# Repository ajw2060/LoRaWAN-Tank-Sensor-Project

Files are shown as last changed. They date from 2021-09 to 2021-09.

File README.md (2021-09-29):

# LoRaWAN-Tank-Sensor-Project
Project files including Schematics, PCB Layouts and code for Tank Sensor modules

The following components are included
1)  KiCad schematics and PCB layouts for the Pump Controller, Tank Top Sensor and Remote switch module.
2)  Micro python code for the Pycom LoPy4 based Tank Top Sensor
3)  Python code for the Raspberry Pi based Pump Controller
4)  Python code for the Raspberry Pi Zero W based remote switch module

The code has been zipped to keep the relevant files together.

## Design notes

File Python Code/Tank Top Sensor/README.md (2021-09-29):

# MillTankSubmersible2021

This is the micropython code for the PyCom Lopy4 microcontroller.  It is intended to do the following.

1) Manage the submersible pressure sensor to detect the depth of water in the tank.
2) Report this water depth along with environmental data via LoRaWAN.

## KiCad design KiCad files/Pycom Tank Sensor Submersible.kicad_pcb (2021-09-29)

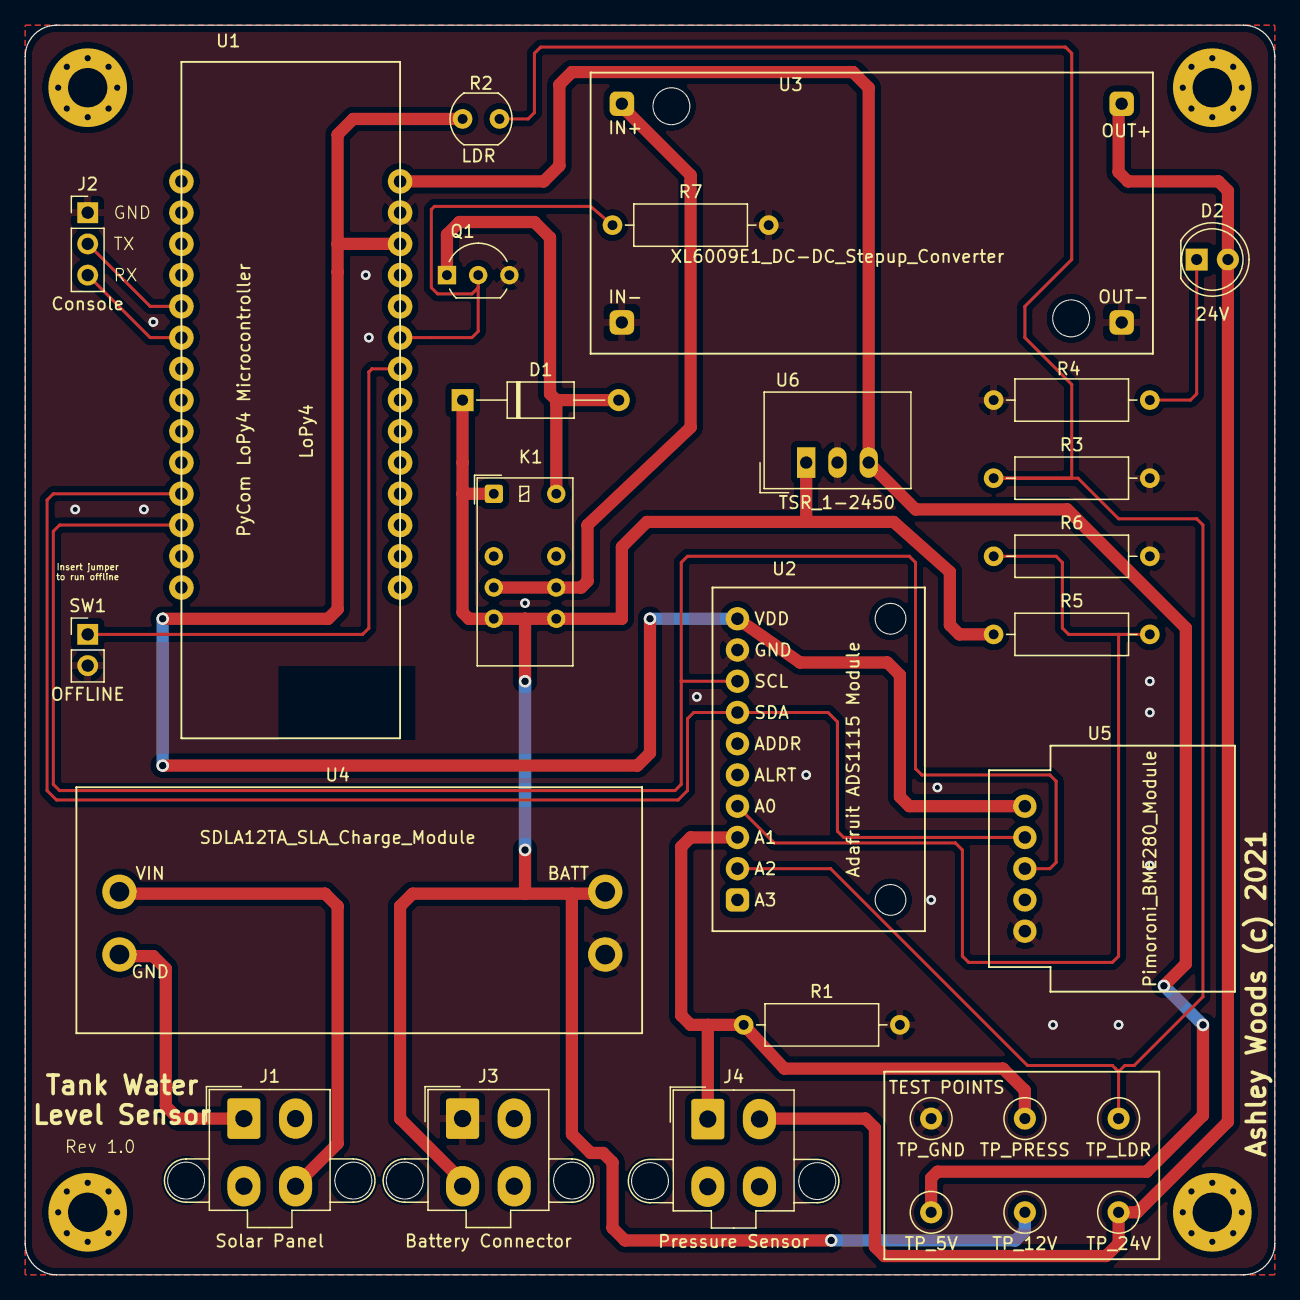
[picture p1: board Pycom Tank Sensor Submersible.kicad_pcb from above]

Board: 2 copper layers, 101.6 x 101.6 mm, 32 parts (0 on the bottom side), 19 nets.

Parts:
D1: D; D_A-405_P12.70mm_Horizontal
D2: +24 LED; LED_D5.0mm
H1, H2, H3, H4: MountingHole; MountingHole_3.2mm_M3_Pad_Via
J1: Solar Panel; Molex_Mini-Fit_Jr_5566-04A2_2x02_P4.20mm_Vertical
J2: Console; PinHeader_1x03_P2.54mm_Vertical
J3: Battery Connector; Molex_Mini-Fit_Jr_5566-04A2_2x02_P4.20mm_Vertical
J4: Pressure Sensor; Molex_Mini-Fit_Jr_5566-04A2_2x02_P4.20mm_Vertical
J5: TP_GND; TestPoint_Loop_D2.60mm_Drill0.9mm_Beaded
J6: TP_5V; TestPoint_Loop_D2.60mm_Drill0.9mm_Beaded
J7: TP_12V; TestPoint_Loop_D2.60mm_Drill0.9mm_Beaded
J8: TP_24V; TestPoint_Loop_D2.60mm_Drill0.9mm_Beaded
J9: TP_PRESS; TestPoint_Loop_D2.60mm_Drill0.9mm_Beaded
J10: TP_LDR; TestPoint_Loop_D2.60mm_Drill0.9mm_Beaded
K1: EC2-12NU; Relay_DPDT_Kemet_EC2
Q1: BS170; TO-92_Inline_Wide
R1: 100R; R_Axial_DIN0309_L9.0mm_D3.2mm_P12.70mm_Horizontal
R2: LDR; R_LDR_5.0x4.1mm_P3mm_Vertical
R3: 1K; R_Axial_DIN0309_L9.0mm_D3.2mm_P12.70mm_Horizontal
R4: 1.5K; R_Axial_DIN0309_L9.0mm_D3.2mm_P12.70mm_Horizontal
R5: 15K; R_Axial_DIN0309_L9.0mm_D3.2mm_P12.70mm_Horizontal
R6: 4.7K; R_Axial_DIN0309_L9.0mm_D3.2mm_P12.70mm_Horizontal
R7: 10K; R_Axial_DIN0309_L9.0mm_D3.2mm_P12.70mm_Horizontal
SW1: OFFLINE; PinHeader_1x02_P2.54mm_Vertical
U1: LoPy4; LoPy_with_headers
U2: Adafruit_ADS1115_Module
U3: XL6009E1_DC-DC_Stepup_Converter; XL6009E1_DC-DC_Converter
U4: SDLA12TA_SLA_Charge_Module; SDLA12TA_Module
U5: Pimoroni_BME280_Module; Pimoroni BME280 Module
U6: TSR_1-2450; Converter_DCDC_TRACO_TSR-1_THT

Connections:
3v3: R2.1, U1.26, U2.10, U5.1
BATTERY+12: D1.1, J3.3, J7.1, K1.1, K1.5, K1.8, R5.1, U4.4, U6.1
BATTLEVEL_SENSE: R5.2, R6.1, U2.4
BOOST24POS: D2.2, J4.2, J8.1, U3.3
BOOST_ENABLE: Q1.2, R7.1, U1.23
BOOST_SUPPLY: K1.4, K1.9, U3.1
BOOST_SWITCH: D1.2, K1.12, Q1.1
CONSOLE_RX: J2.3, U1.6
CONSOLE_TX: J2.2, U1.5
GND: J2.1, J3.1, J5.1, Q1.3, R1.2, R3.2, R4.2, R6.2, R7.2, SW1.2, U1.27, U2.9, U3.2, U3.4, U4.3, U5.5, U6.2
LDR_SENSE: J10.1, R2.2, R3.1, U2.2
unnamed: D2.1, R4.1
OFFLINE_MODE: SW1.1, U1.22
PANEL_NEG: J1.1, U4.2
PANEL_POS: J1.4, U4.1
PRESS_SENSE: J4.1, J9.1, R1.1, U2.3
SCL: U1.12, U2.8, U5.3
SDA: U1.11, U2.7, U5.2
VCC: J6.1, U1.28, U6.3

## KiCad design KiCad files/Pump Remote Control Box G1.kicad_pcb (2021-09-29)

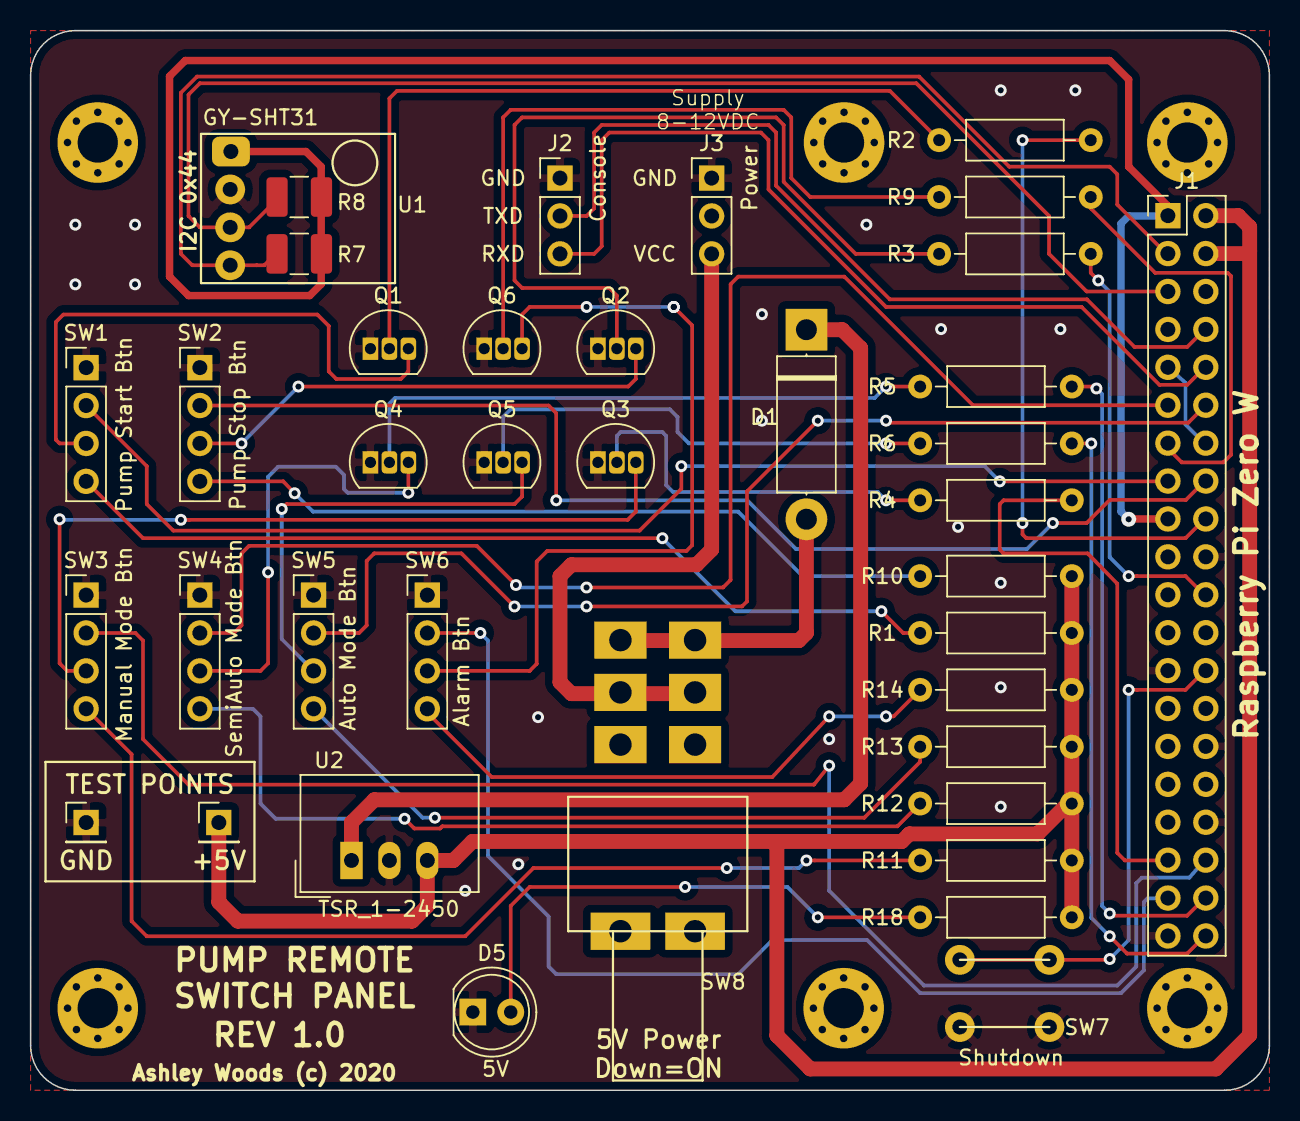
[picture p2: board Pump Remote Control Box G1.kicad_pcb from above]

Board: 2 copper layers, 83.0 x 71.0 mm, 44 parts (0 on the bottom side), 42 nets.

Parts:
D1: D; D_5W_P12.70mm_Horizontal
D5: 5V; LED_D5.0mm
H1, H2, H3, H4, H5, H6: Mount; MountingHole_2.7mm_M2.5_Pad_Via
J1: Raspberry_Pi_2_3; PinHeader_2x20_P2.54mm_Vertical
J2: Serial Console Connector; PinHeader_1x03_P2.54mm_Vertical
J3: Power Input Connector; PinHeader_1x03_P2.54mm_Vertical
Q1, Q2, Q3, Q4, Q5, Q6: P2N2222A; TO-92L_Inline
R1, R10, R11, R12, R13, R14, R18: 220R; R_Axial_DIN0207_L6.3mm_D2.5mm_P10.16mm_Horizontal
R2, R3, R4, R5, R6, R9: 4k3; R_Axial_DIN0207_L6.3mm_D2.5mm_P10.16mm_Horizontal
R7, R8: 10K; R_1210_3225Metric_Pad1.42x2.65mm_HandSolder
SW1: Pump Start Button; PinHeader_1x04_P2.54mm_Vertical
SW2: Pump Stop Button; PinHeader_1x04_P2.54mm_Vertical
SW3: Manual Mode Button; PinHeader_1x04_P2.54mm_Vertical
SW4: Semiauto Mode Button; PinHeader_1x04_P2.54mm_Vertical
SW5: Auto Mode Button; PinHeader_1x04_P2.54mm_Vertical
SW6: Alarm Button; PinHeader_1x04_P2.54mm_Vertical
SW7: Shutdown; PCB Switch RS 479-1413
SW8: SW_DPDT; Switch DPDT Jaycar ST0365
TP1: TP GND; PinHeader_1x01_P2.54mm_Vertical
TP2: TP +5V; PinHeader_1x01_P2.54mm_Vertical
U1: GY_SHT31-Breakout-pycom; GY_SHT31_Breakout
U2: TSR_1-2450; Converter_DCDC_TRACO_TSR-1_THT

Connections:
3v3: J1.1, J1.17, R7.1, R8.1, U1.1
5V: J1.2, J1.4, R1.1, R10.1, R11.1, R12.1, R13.1, R14.1, R18.2, TP2.1, U2.3
Alarm_Button: J1.37, SW6.2
Alarm_Button_LED: J1.13, R9.2
Auto_Mode_Button: J1.12, SW5.2
Auto_Mode_Button_LED: J1.40, R6.2
GND: D5.1, J1.6, J1.9, J1.14, J1.20, J1.25, J1.30, J1.34, J1.39, J2.1, J3.1, Q1.1, Q2.1, Q3.1, Q4.1, Q5.1, Q6.1, SW1.1, SW2.1, SW3.1, SW4.1, SW5.1, SW6.1, SW7.3, SW7.4, TP1.1, U1.2, U2.2
Manual_Mode_Button: J1.36, SW3.2
Manual_Mode_Button_LED: J1.35, R4.2
unnamed: D1.1, U2.1
unnamed: D1.2, SW8.1, SW8.4
unnamed: D5.2, R18.1
unnamed: J3.3, SW8.2, SW8.5
unnamed: Q1.2, R2.1
unnamed: Q1.3, SW1.3
unnamed: Q2.2, R3.1
unnamed: Q2.3, SW2.3
unnamed: Q3.2, R4.1
unnamed: Q3.3, SW3.3
unnamed: Q4.2, R5.1
unnamed: Q4.3, SW4.3
unnamed: Q5.2, R6.1
unnamed: Q5.3, SW5.3
unnamed: Q6.2, R9.1
unnamed: Q6.3, SW6.3
unnamed: R1.2, SW1.4
unnamed: R10.2, SW2.4
unnamed: R11.2, SW3.4
unnamed: R12.2, SW4.4
unnamed: R13.2, SW5.4
unnamed: R14.2, SW6.4
Pump_Start_Button: J1.15, SW1.2
Pump_Start_Button_LED: J1.18, R2.2
Pump_Stop_Button: J1.16, SW2.2
Pump_Stop_Button_LED: J1.22, R3.2
RXD: J1.10, J2.3
SCL: J1.5, R8.2, U1.3
SDA: J1.3, R7.2, U1.4
SHUTDOWN: J1.26, SW7.1, SW7.2
Semiauto_Mode_Button: J1.11, SW4.2
Semiauto_Mode_Button_LED: J1.38, R5.2
TXD: J1.8, J2.2

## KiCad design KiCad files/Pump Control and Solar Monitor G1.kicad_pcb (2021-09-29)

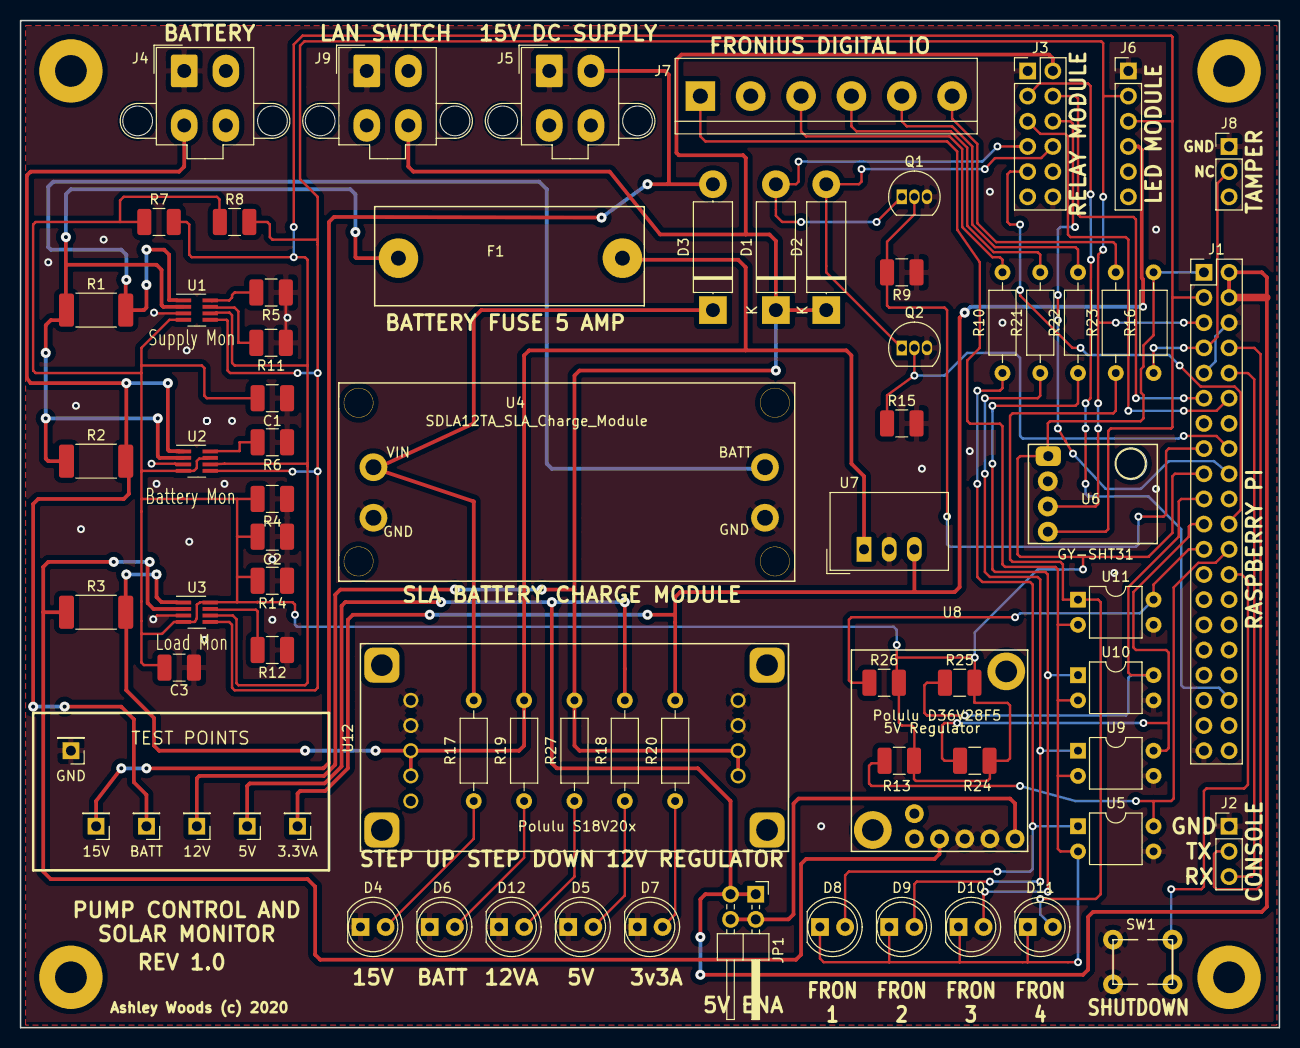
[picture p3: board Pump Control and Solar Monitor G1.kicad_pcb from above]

Board: 2 copper layers, 127.0 x 101.6 mm, 74 parts (0 on the bottom side), 50 nets.

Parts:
C1, C2, C3: 0.1uF; C_1210_3225Metric_Pad1.42x2.65mm_HandSolder
D1, D2: FLYBACK DIODE; D_5W_P12.70mm_Horizontal
D3: Polarity Protection; D_5W_P12.70mm_Horizontal
D4: 15V Present; LED_D5.0mm
D5: 5V Present; LED_D5.0mm
D6: BATTERY Present; LED_D5.0mm
D7: 3v3AUX Present; LED_D5.0mm
D8: Fron1; LED_D5.0mm
D9: Fron2; LED_D5.0mm
D10: Fron3; LED_D5.0mm
D11: Fron4; LED_D5.0mm
D12: 12VA Supply; LED_D5.0mm
F1: Fuse 5 AMP; Wuth Electronik PCB TTH Fuse Holder
J1: Raspberry_Pi_2_3; PinHeader_2x20_P2.54mm_Vertical
J2: Serial Console Connector; PinHeader_1x03_P2.54mm_Vertical
J3: Switch Module Connector; PinHeader_2x06_P2.54mm_Vertical
J4: Battery Connector; Molex_Mini-Fit_Jr_5566-04A2_2x02_P4.20mm_Vertical
J5: DC Power Supply Conector; Molex_Mini-Fit_Jr_5566-04A2_2x02_P4.20mm_Vertical
J6: LED Module Connector; PinHeader_1x06_P2.54mm_Vertical
J7: Plug in Screw_Terminal; TerminalBlock_bornier-6_P5.08mm
J8: Tamper Switch Connector; PinHeader_1x03_P2.54mm_Vertical
J9: Netgear Power; Molex_Mini-Fit_Jr_5566-04A2_2x02_P4.20mm_Vertical
JP1: 5V Enable Jumper; PinHeader_2x02_P2.54mm_Horizontal_DualConnected
Q1, Q2: BS170; TO-92_Inline
R1, R2, R3: 0.1R; R_2512_6332Metric_Pad1.52x3.35mm_HandSolder
R4, R5, R6, R7, R8, R9, R11, R12, R13, R14, R15, R24, R25, R26: 10K; R_1210_3225Metric_Pad1.42x2.65mm_HandSolder
R10, R21, R22, R23: 540R; R_Axial_DIN0207_L6.3mm_D2.5mm_P10.16mm_Horizontal
R16: 10K; R_Axial_DIN0207_L6.3mm_D2.5mm_P10.16mm_Horizontal
R17, R20: 1K; R_Axial_DIN0207_L6.3mm_D2.5mm_P10.16mm_Horizontal
R18: 220R; R_Axial_DIN0207_L6.3mm_D2.5mm_P10.16mm_Horizontal
R19, R27: 820R; R_Axial_DIN0207_L6.3mm_D2.5mm_P10.16mm_Horizontal
SW1: PCB_Switch_RS479-1413; PCB Switch RS 479-1413
TP1: TP GND; PinHeader_1x01_P2.54mm_Vertical
TP2: TP 15V; PinHeader_1x01_P2.54mm_Vertical
TP3: TP Battery; PinHeader_1x01_P2.54mm_Vertical
TP4: TP 12VA; PinHeader_1x01_P2.54mm_Vertical
TP5: TP 5V; PinHeader_1x01_P2.54mm_Vertical
TP6: TP 3v3A; PinHeader_1x01_P2.54mm_Vertical
U1, U2, U3: INA219AIDCNR; SOT-23-8_Handsoldering
U4: SDLA12TA_SLA_Charge_Module; SDLA12TA_Module
U5, U9, U10, U11: PC817; DIP-4_W7.62mm
U6: GY_SHT31 Module; GY_SHT31_Breakout
U7: TSR_1-2433; Converter_DCDC_TRACO_TSR-1_THT
U8: Polulu D36V28F5 5V Regulator; Polulu_D36V28F5_Regulator
U12: Polulu_S18V20F12_Voltage_Regulator; Polulu_S18V20x_Regulators

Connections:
3v3: C1.2, C2.2, C3.2, J1.1, J1.17, R4.2, R7.1, R8.1, R13.2, R14.2, R16.2, R24.2, R25.2, R26.2, U1.4, U2.4, U2.7, U3.4, U3.8, U6.1
5V: J1.2, J1.4, JP1.1, R18.2, TP5.1
+3.3VA: J6.4, R20.2, TP6.1, U7.3
+12VA: D1.1, D2.1, J3.2, J9.4, R27.2, TP4.1, U12.6, U12.7
+15V: D3.1, R17.2, U4.1
AC_Phase1_Present: J1.36, J3.3
AC_Phase2_Present: J1.11, J3.4
AC_Phase3_Present: J1.12, J3.5
BATTERY+: J4.3, R2.2, TP3.1, U2.1
BATTERY_SUPPLY: F1.1, R3.2, R19.2, U3.1, U7.1, U12.3, U12.4
FRONIUS_1: J1.24, R13.1, U5.4
FRONIUS_2: J1.21, R24.1, U9.4
FRONIUS_3: J1.19, R25.1, U10.4
FRONIUS_4: J1.23, R26.1, U11.4
FRONIUS_GND: D8.1, D9.1, D10.1, D11.1, J7.1, U5.2, U9.2, U10.2, U11.2
FRONIUS_RAW_1: J7.3, R10.2
FRONIUS_RAW_2: J7.4, R21.2
FRONIUS_RAW_3: J7.5, R22.2
FRONIUS_RAW_4: J7.6, R23.2
GND: C1.1, C2.1, C3.1, D4.1, D5.1, D6.1, D7.1, D12.1, J1.6, J1.9, J1.14, J1.20, J1.25, J1.30, J1.34, J1.39, J2.1, J3.1, J3.12, J4.1, J5.1, J6.1, J8.1, J9.1, Q1.3, Q2.3, R4.1, R5.1, R6.1, R9.1, R11.1, R12.1, R14.1, R15.2, SW1.3, SW1.4, TP1.1, U1.3, U2.3, U3.3, U4.2, U4.3, U5.3, U6.2, U7.2, U8.4, U8.5, U9.3, U10.3, U11.3, U12.1, U12.2, U12.8, U12.9
unnamed: D3.2, J5.2, TP2.1
unnamed: D4.2, R17.1
unnamed: D5.2, R18.1
unnamed: D6.2, R19.1
unnamed: D7.2, R20.1
unnamed: D8.2, R10.1, U5.1
unnamed: D9.2, R21.1, U9.1
unnamed: D10.2, R22.1, U10.1
unnamed: D11.2, R23.1, U11.1
unnamed: D12.2, R27.1
unnamed: F1.2, R1.1, R2.1, U1.2, U2.2
unnamed: JP1.2, U8.6
unnamed: R1.2, U1.1, U4.4
unnamed: R3.1, U3.2, U8.3
unnamed: R5.2, U1.8
unnamed: R6.2, U2.8
unnamed: R11.2, U1.7
unnamed: R12.2, U3.7
PUMP_FAULT: J1.22, J3.9
PUMP_RUNNING: J1.18, J3.6
PUMP_START_PULSE: J1.15, Q1.2, R9.2
PUMP_START_RELAY: D1.2, J3.7, Q1.1
PUMP_STOP_PULSE: J1.16, Q2.2, R15.1
PUMP_STOP_RELAY: D2.2, J3.8, Q2.1
RXD: J1.10, J2.3
SCL: J1.5, J6.2, R8.2, U1.5, U2.5, U3.5, U6.3
SDA: J1.3, J6.3, R7.2, U1.6, U2.6, U3.6, U6.4
SHUTDOWN: J1.26, SW1.1, SW1.2
TAMPER: J1.7, J8.2, R16.1
TXD: J1.8, J2.2

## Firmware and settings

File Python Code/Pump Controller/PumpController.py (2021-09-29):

# This script will do the following
# - monitor the various GPIO on the Pi for changes and act accordingly


# Changes
# 2020-10-24    Initial version.  This was added under Jupyter.
# 2020-10-31    Added operation mode feature for manual/semi/auto modes receivable via MQTT.
# 2020-11-05    Added subscriber for tank level data via MQTT.
# 2021-07-01    Added better error handler to received MQTT message for tank water level messages.
# 2021-07-18	Added log rotation.
# 2021-07-21    Added tank data keys to status dictionary so this gets reported in status updates also.
# 2021-07-27    Added more logging to pump start/stop processing in automatic mode (to show variables at entry)
# 2021-07-27    Added 'pump turn off' processing in automatic mode.
# 2021-07-28    Simplified logging around receipt of command messages.

from gpiozero import Button# import button from the Pi GPIO library
#from gpiozero import DigitalOutputDevice
#from gpiozero import DigitalInputDevice
from gpiozero import OutputDevice
from gpiozero import CPUTemperature

from ina219 import INA219
from ina219 import DeviceRangeError

import time

import os # imports OS library for Shutdown control
import logging
import logging.handlers
import platform
import sys
from signal import pause
import yaml
import json
import paho.mqtt.client as mqtt
import pprint

import datetime
import threading
import schedule

import smbus

#import socket
#import asyncio



# ---- Define the GPIO pins used by each sense or control line
# The shutdown_button on GPIO7 (Pin 26) is not initialised here as it is used in the separate shutdown script.
phase1_present_sense = Button(16)       #Pin 36
phase2_present_sense = Button(17)       #Pin 11
phase3_present_sense = Button(18)       #Pin 12

pump_running_sense = Button(24)         #Pin 18
pump_fault_sense = Button(25)           #Pin 22

tamper_switch_sense = Button(4)         #Pin 7
fronius_digital1_sense = Button(8)      #Pin 24
fronius_digital2_sense = Button(9)      #Pin 21
fronius_digital3_sense = Button(10)     #Pin 19
fronius_digital4_sense = Button(11)     #Pin 23

pump_start_pulse = OutputDevice(22, active_high=True, initial_value=False, pin_factory=None)       #Pin 15
pump_stop_pulse = OutputDevice(23, active_high=True, initial_value=False, pin_factory=None)        #Pin 16



# ---- Scheduling timers
# next_run_hourly = time.time()
# run_interval_hourly = 3600              # To schedule things every hour (but not necessarily on the hour)


# ---------- Configuration load from YAML -----------------------------------------------------------------------------
def yaml_loader(filepath):
    try:
        with open(filepath, "r") as file_descriptor:
            config_data = yaml.load(file_descriptor, Loader=yaml.FullLoader)    # Should avoid the unsafe warning
        return config_data
    except:
        print(f"ERROR 5.  Unable to open the YAML configuration file at {filepath}.")
        exit(5)


# ---------- Get the temperature and humidity from the SHT31 sensor ---------------------------------------------------
def getEnclosureTempHumi():
    #print("Getting enclosure temperature and humidity from SHT31 sensor.")
    # Get I2C bus
    bus = smbus.SMBus(1)

    # SHT31 address, 0x44(68)
    bus.write_i2c_block_data(0x44, 0x2C, [0x06])
    time.sleep(0.5)

    # SHT31 address, 0x44(68)
    # Read data back from 0x00(00), 6 bytes
    # Temp MSB, Temp LSB, Temp CRC, Humididty MSB, Humidity LSB, Humidity CRC
    data = bus.read_i2c_block_data(0x44, 0x00, 6)

    # Convert the data
    temp = data[0] * 256 + data[1]
    cTemp = -45 + (175 * temp / 65535.0)
    humidity = 100 * (data[3] * 256 + data[4]) / 65535.0

    # Print the results
    #print("..SHT31 Temperature : %.1f C" %cTemp)
    #print("..SHT31 Humidity    : %.0f %%RH" %humidity)

    # And stuff these into the dictionary
    system_status['environment_state']['enclosure_temperature'] = format(cTemp,'.1f')
    system_status['environment_state']['enclosure_humidity'] = format(humidity,'.0f')


# ---- Get system uptime ----------------------------------------------------------------------------------------------
def get_system_uptime():
    with open('/proc/uptime', 'r') as f:
        uptime_seconds = float(f.readline().split()[0])
        return int(uptime_seconds)


# ---------- Get Raspberry Pi CPU Temperature -------------------------------------------------------------------------
def getCpuTemperature():
    #print("Getting CPU temperature from Raspberry Pi CPU.")
    cpu = CPUTemperature()
    #print('..CPU  temperature  : {}C'.format(cpu.temperature))
    # And stuff it into the dictionary
    system_status['environment_state']['cpu_temperature'] = format(cpu.temperature,'.1f')


# ---------- Publish a generic environmental alarm --------------------------------------------------------------------
def publishEnvironmentAlarm(alarmNumber, alarmState):
    # This will ultimately publish an environment alarm
    #print("XXXXXXXXX - Environment alarm publish stub.  Alarm No=[" + str(alarmNumber) + "].  Alarm State =[" + str(alarmState) +"]")
    '''
        Received parameters are as follows.
        alarmNumber = alarm number
        alarmState.  1=New alarm.  0=Cleared alarm.
    '''
    logger.debug("Publish the alarm message.")

    publish_generic_message('Alarm Condition Detected', topic_pump_status, system_status)


# ---------- Now check if we have any alarm conditions present that need to be reported -------------------------------
def checkForAlarms():
    logger.debug('Running a check of all environment conditions (temp, humidity, sensors, etc) now.')
    '''
        There are many possible alarm conditions to inspect.
        Each one is done individually and a message is published for fresh alarms and cleared alarms (but not for ongoing alarms).
        '''
    checkAlarm01()      # Enclosure temperature
    checkAlarm02()      # Enclosure humidity
    checkAlarm03()      # CPU Temperature
    checkAlarm04()      # Still receiving updates from water level sensor
    checkAlarm05()      # Battery voltage
    checkAlarm06()      # Battery is not discharging


# ---------- Alarm check 01 - Enclosure over temperature --------------------------------------------------------------
def checkAlarm01():
    #logger.debug('.Alarm check 01 - Check for enclosure over-temperature alarm.')
    global enclosure_temp_alarm_base_value
    global enclosure_temp_alarm_recovery_value
    global enclosure_temp_alarm_working_value

    if float(system_status['environment_state']['enclosure_temperature']) < enclosure_temp_alarm_working_value and not system_status['alarms']['enclosure_overtemperature']:
        # All good and nothing to do
        #logger.debug(f"..NORMAL.  Enclosure temperature [{float(system_status['environment_state']['enclosure_temperature']):.1f}] is below threshold of [{float(enclosure_temp_alarm_working_value):.1f}].")
        pass

    elif float(system_status['environment_state']['enclosure_temperature']) >= enclosure_temp_alarm_working_value and not system_status['alarms']['enclosure_overtemperature']:
        # This is a fresh over temperature alarm.  Set the enclosure over-temp alarm flag and publish an alarm.
        logger.debug(f"..NEW ALARM.  Enclosure temperature [{float(system_status['environment_state']['enclosure_temperature']):.1f}] is at or above threshold of [{float(enclosure_temp_alarm_working_value):.1f}].")
        system_status['alarms']['enclosure_overtemperature'] = True
        publishEnvironmentAlarm(1,1)
        # Bump the threshold down to introduce hysterisis for recovery.
        logger.debug(f"..Hysterisis lowering the over-temp alarm threshold from [{enclosure_temp_alarm_working_value:.1f}] to [{enclosure_temp_alarm_recovery_value:.1f}].")
        enclosure_temp_alarm_working_value = enclosure_temp_alarm_recovery_value

    elif float(system_status['environment_state']['enclosure_temperature']) >= enclosure_temp_alarm_working_value and system_status['alarms']['enclosure_overtemperature']:
        # This constitutes an ongoing alarm which does not need to be published again because it has already been done when the condition was first detected.
        logger.debug(f"..CONTINUED ALARM.  Enclosure temperature [{float(system_status['environment_state']['enclosure_temperature']):.1f}] remains above threshold of [{float(enclosure_temp_alarm_working_value):.1f}].")

    elif float(system_status['environment_state']['enclosure_temperature']) < enclosure_temp_alarm_working_value and system_status['alarms']['enclosure_overtemperature']:
        # This is the recovery of an ongoing alarm.  Clear the enclosure over-temp alarm flag and publish a message to indicate recovery.
        logger.debug(f"..CLEARED ALARM.  Enclosure temperature [{float(system_status['environment_state']['enclosure_temperature']):.1f}] is now below threshold of [{float(enclosure_temp_alarm_working_value):.1f}].")
        system_status['alarms']['enclosure_overtemperature'] = False
        publishEnvironmentAlarm(1,0)
        # Restore threshold temperature.
        logger.debug(f"..Hysterisis restoring the over-temp alarm threshold from [{enclosure_temp_alarm_working_value:.1f}] to [{enclosure_temp_alarm_base_value:.1f}].")
        enclosure_temp_alarm_working_value = enclosure_temp_alarm_base_value

    else:
        #logging.error("ERROR 101.  Problem with interrogating enclosure temperature.")
        print("ERROR 101.  Problem with interrogating enclosure temperature.")


# ---------- Alarm check 02 - Enclosure over humidity -----------------------------------------------------------------
def checkAlarm02():
    #logger.debug('.Alarm check 02 - Check for enclosure over-humidity alarm.')
    global enclosure_humidity_alarm_base_value
    global enclosure_humidity_alarm_recovery_value
    global enclosure_humidity_alarm_working_value

    if float(system_status['environment_state']['enclosure_humidity']) < enclosure_humidity_alarm_working_value and not system_status['alarms']['enclosure_overhumidity']:
        # All good and nothing to do
        #logger.debug(f"..NORMAL.  Enclosure humidity [{float(system_status['environment_state']['enclosure_humidity']):.0f}] is below threshold of [{float(enclosure_humidity_alarm_working_value):.0f}].")
        pass

    elif float(system_status['environment_state']['enclosure_humidity']) >= enclosure_humidity_alarm_working_value and not system_status['alarms']['enclosure_overhumidity']:
        # This is a fresh over humidity alarm.  Set the enclosure over-humidity alarm flag and publish an alarm.
        logger.debug(f"..NEW ALARM.  Enclosure humidity [{float(system_status['environment_state']['enclosure_humidity']):.1f}] is at or above threshold of [{float(enclosure_humidity_alarm_working_value):.1f}].")
        system_status['alarms']['enclosure_overhumidity'] = True
        publishEnvironmentAlarm(2,1)
        # Bump the threshold down to introduce hysterisis for recovery.
        logger.debug(f"..Hysterisis lowering the over-humidity alarm threshold from [{enclosure_humidity_alarm_working_value:.0f}] to [{enclosure_humidity_alarm_recovery_value:.0f}].")
        enclosure_humidity_alarm_working_value = enclosure_humidity_alarm_recovery_value

    elif float(system_status['environment_state']['enclosure_humidity']) >= enclosure_humidity_alarm_working_value and system_status['alarms']['enclosure_overhumidity']:
        # This constitutes an ongoing alarm which does not need to be published again because it has already been done when the condition was first detected.
        logger.debug(f"..CONTINUED ALARM.  Enclosure humidity [{float(system_status['environment_state']['enclosure_humidity']):.0f}] remains above threshold of [{float(enclosure_humidity_alarm_working_value):.0f}].")

    elif float(system_status['environment_state']['enclosure_humidity']) < enclosure_humidity_alarm_working_value and system_status['alarms']['enclosure_overhumidity']:
        # This is the recovery of an ongoing alarm.  Clear the enclosure over-humidity alarm flag and publish a message to indicate recovery.
        logger.debug(f"..CLEARED ALARM.  Enclosure humidity [{float(system_status['environment_state']['enclosure_humidity']):.0f}] is now below threshold of [{float(enclosure_humidity_alarm_working_value):.0f}].")
        system_status['alarms']['enclosure_overhumidity'] = False
        publishEnvironmentAlarm(2,0)
        # Restore threshold humidity.
        logger.debug(f"..Hysterisis restoring the over-humidity alarm threshold from [{enclosure_humidity_alarm_working_value:.0f}] to [{enclosure_humidity_alarm_base_value:.0f}].")
        enclosure_humidity_alarm_working_value = enclosure_humidity_alarm_base_value

    else:
        logger.error("ERROR 201.  Problem with interrogating enclosure humidity.")


# ---------- Alarm check 03 - CPU over temperature --------------------------------------------------------------------
def checkAlarm03():
    #logger.debug('.Alarm check 03 - Check for CPU over-temperature alarm.')
    global cpu_temp_alarm_base_value
    global cpu_temp_alarm_recovery_value
    global cpu_temp_alarm_working_value

    if float(system_status['environment_state']['cpu_temperature']) < cpu_temp_alarm_working_value and not system_status['alarms']['cpu_overtemperature']:
        # All good and nothing to do
        #logger.debug(f"..NORMAL.  CPU temperature [{float(system_status['environment_state']['cpu_temperature']):.1f}] is below threshold of [{float(cpu_temp_alarm_working_value):.1f}].")
        pass

    elif float(system_status['environment_state']['cpu_temperature']) >= cpu_temp_alarm_working_value and not system_status['alarms']['cpu_overtemperature']:
        # This is a fresh over temperature alarm.  Set the cpu over-temp alarm flag and publish an alarm.
        logger.debug(f"..NEW ALARM.  CPU temperature [{float(system_status['environment_state']['cpu_temperature']):.1f}] is at or above threshold of [{float(cpu_temp_alarm_working_value):.1f}].")
        system_status['alarms']['cpu_overtemperature'] = True
        publishEnvironmentAlarm(3,1)
        # Bump the threshold down to introduce hysterisis for recovery.
        logger.debug(f"..Hysterisis lowering the CPU over-temp alarm threshold from [{cpu_temp_alarm_working_value:.1f}] to [{cpu_temp_alarm_recovery_value:.1f}].")
        cpu_temp_alarm_working_value = cpu_temp_alarm_recovery_value

    elif float(system_status['environment_state']['cpu_temperature']) >= cpu_temp_alarm_working_value and system_status['alarms']['cpu_overtemperature']:
        # This constitutes an ongoing alarm which does not need to be published again because it has already been done when the condition was first detected.
        logger.debug(f"..CONTINUED ALARM.  CPU temperature [{float(system_status['environment_state']['cpu_temperature']):.1f}] remains above threshold of [{float(cpu_temp_alarm_working_value):.1f}].")

    elif float(system_status['environment_state']['cpu_temperature']) < cpu_temp_alarm_working_value and system_status['alarms']['cpu_overtemperature']:
        # This is the recovery of an ongoing alarm.  Clear the cpu over-temp alarm flag and publish a message to indicate recovery.
        logger.debug(f"..CLEARED ALARM.  CPU temperature [{float(system_status['environment_state']['cpu_temperature']):.1f}] is now below threshold of [{float(cpu_temp_alarm_working_value):.1f}].")
        system_status['alarms']['cpu_overtemperature'] = False
        publishEnvironmentAlarm(3,0)
        # Restore threshold temperature.
        logger.debug(f"..Hysterisis restoring the CPU over-temp alarm threshold from [{cpu_temp_alarm_working_value:.1f}] to [{cpu_temp_alarm_base_value:.1f}].")
        cpu_temp_alarm_working_value = cpu_temp_alarm_base_value

    else:
        logger.error("ERROR 302.  Problem with interrogating CPU temperature.")


# ---------- Alarm check 04 - Confirm we are still recieving live updates from the water level sensor -----------------
def checkAlarm04():
    global tank_waterlevel_maximum_age
    #logger.debug(f".Alarm check 04 - Check that level sensor updates received (at worst) every [{float(tank_waterlevel_maximum_age)/3600:.2f}] hours.")

    if time.time() - float(tank_water_status['tank_waterlevel_lastupdate']) < tank_waterlevel_maximum_age and not system_status['alarms']['water_level_sensor_offline']:
        # All good - must have received a recent water level update.
        #logger.debug(f"..NORMAL.  Time since last update [{(time.time() - float(tank_water_status['tank_waterlevel_lastupdate']))/3600:.2f}] hours.")
        pass

    elif  time.time() - float(tank_water_status['tank_waterlevel_lastupdate']) >= tank_waterlevel_maximum_age and not system_status['alarms']['water_level_sensor_offline']:
        # This is a fresh alarm.  The sensor must have recently stopped sending updates.
        logger.debug(f"..NEW ALARM.  Sensor has gone offline.  Time since last update [{(time.time() - float(tank_water_status['tank_waterlevel_lastupdate']))/3600:.2f}] hours.")
        system_status['alarms']['water_level_sensor_offline'] = True
        publishEnvironmentAlarm(4,1)

    elif time.time() - float(tank_water_status['tank_waterlevel_lastupdate']) >= tank_waterlevel_maximum_age and system_status['alarms']['water_level_sensor_offline']:
        # This is a continuing alarm.  Sensor remains offline.
        logger.debug(f"..CONTINUED ALARM.  Sensor remains offline.  Time since last update [{(time.time() - float(tank_water_status['tank_waterlevel_lastupdate']))/3600:.2f}] hours.")

    elif time.time() - float(tank_water_status['tank_waterlevel_lastupdate']) < tank_waterlevel_maximum_age and system_status['alarms']['water_level_sensor_offline']:
        # This is the recovery of the alarm.  Sensor has started sending water level updates again.
        logger.debug(f"..CLEARED ALARM.  Sensor back online.  Time since last update [{(time.time() - float(tank_water_status['tank_waterlevel_lastupdate']))/3600:.2f}] hours.")
        system_status['alarms']['water_level_sensor_offline'] = False
        publishEnvironmentAlarm(4,0)


# ---------- Alarm check 05 - Confirm the battery level is above threshold --------------------------------------------
def checkAlarm05():
    global battery_low_voltage_alarm_base_value
    global battery_low_voltage_alarm_recovery_value
    global battery_low_voltage_alarm_working_value

    #logger.debug(f".Alarm check 05 - Check if the battery voltage is above the threshold of [{battery_low_voltage_alarm_base_value}] volts.")
    #decorativeStatusDumper("Alarm 05")
    if system_status['power']['battery_voltage'] > battery_low_voltage_alarm_working_value and not system_status['alarms']['battery_low'] :
        # All good - battery is fine
        #logger.debug(f"..NORMAL.  Battery voltage [{system_status['power']['battery_voltage']}] is above threshold of [{battery_low_voltage_alarm_base_value}].")
        pass

    elif system_status['power']['battery_voltage'] <= battery_low_voltage_alarm_working_value and not system_status['alarms']['battery_low']:
        # Battery low has just been detected
        system_status['alarms']['battery_low'] = True
        logger.debug(f"..NEW ALARM.  Battery voltage of [{system_status['power']['battery_voltage']}] is at or below threshold of [{battery_low_voltage_alarm_working_value}] volts.")
        # Bump the threshold down to introduce hysterisis for recovery.
        logger.debug(f"..Hysterisis raising the low battery alarm threshold from [{battery_low_voltage_alarm_working_value:.1f}] to [{battery_low_voltage_alarm_recovery_value:.1f}].")
        battery_low_voltage_alarm_working_value = battery_low_voltage_alarm_recovery_value
        publishEnvironmentAlarm(5,1)

    elif system_status['power']['battery_voltage'] <= battery_low_voltage_alarm_working_value and system_status['alarms']['battery_low']:
        # Stale low battery alarm
        logger.debug(f"..CONTINUED ALARM.  Battery voltage now at [{system_status['power']['battery_voltage']}].  Battery is still going flat.")

    elif system_status['power']['battery_voltage'] > battery_low_voltage_alarm_working_value and system_status['alarms']['battery_low']:
        # Battery voltage has recovered so restore the threshold and clear the alarm flag
        logger.debug(f"..CLEARED ALARM.  Battery voltage of [{system_status['power']['battery_voltage']}] has recovered to be above [{battery_low_voltage_alarm_working_value}].")
        # Restore threshold value.
        logger.debug(f"..Hysterisis restoring the low battery alarm threshold from [{battery_low_voltage_alarm_working_value:.1f}] to [{battery_low_voltage_alarm_base_value:.1f}].")
        battery_low_voltage_alarm_working_value = battery_low_voltage_alarm_base_value
        # Clear the alarm flag
        system_status['alarms']['battery_low'] = False
        publishEnvironmentAlarm(5,0)

    else:
        logger.error("ERROR 105.  Problem with interrogating battery voltage.")
        print("ERROR 105.  Problem with interrogating battery voltage.")
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

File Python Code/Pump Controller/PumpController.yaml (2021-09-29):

# This is the YAML configuration file for the Solar Monitor Pump Control (SMPC) system.

#  DO NOT USE TABS IN THIS FILE, or if you do, ensure the editor converts them to spaces.


station_configuration:       # This defines the station running the script
    mqtt_station_name:  "xx"
    mqtt_user_name:     "yy"
    mqtt_user_password: "zz"

broker_configuration:        #This defines the broker we will connect to
    broker_name: "bbbb.com.au"
    broker_port: 1883
    broker_timeout: 60

subscribe_topic_names:       # This identifies topics to subscribe to 
    topic_pump_cmd:         "topic1"           # This topic is used for all commands such as on/off as well as mode changes
    topic_tank_waterlevel:  "topic2"  # This identifies which tank level to subscribe to. Must match publish topic in TankDataWriter.

publish_topic_names:         # This identifies topics to use when publishing 
    topic_pump_cmdack:  "topic3"
    topic_pump_status:  "topic4"
    topic_pump_lwt:     "topic/lwt"

system_configuration:           # This sets the default startup mode
    # Valid startup modes are as follows.  Any other value defaults to manual.
    # 1=manual, 2=semi-automatic, 3=automatic 
    system_startup_mode: 2

home_assistant_configuration:       # These bits are specific to Home Assistant and look after registering this device in HA.
    ha_announce_on_start: True      
    ha_announce_topic:  "homeassistant/binarysensor/pumpcontroller/config"
    ha_available_topic: "homeassistant/binarysensor/pumpcontroller/available"
    ha_config_data:
        name: "Whatever Pump Controller"
        command_topic: "topic"
        payload_on: "1"
        payload_off: "0"
        availability_topic: "homeassistant/switch/pumpcontroller/available"
        state_topic: "homeassistant/switch/pumpcontroller/available"
        unique_id: "haid"


tank_level_thresholds:       # This specifies the water level at which the pump switches on and off when running in automatic mode
    tank_threshold_low:  0.3
    tank_threshold_high: 0.95
    tank_waterlevel_maximum_age: 9000   
    
    # This 'tank_waterlevel_maximum_age' is the maximum age in seconds permitted between water level updates.  
    # If the recorded water level reading is older than this then the reading is considered out of date (stale).
    # This is also therefore the dead time alarm for the water level updates.  If no update is received in this window
    # then the sending sensor is declared offline and then semi-automatic and automatic modes will turn the pump off to be safe.
    

environment_thresholds:      # These define the trigger levels and recovery deltas for temperature and humidity alarms.
    enclosure_temp_alarm_setting: 45
    enclosure_humidity_alarm_setting: 90
    cpu_temp_alarm_setting: 65
    battery_low_voltage_alarm_setting: 11.5     
    

environment_threshold_recovery_hysterisis:      # Suggest not messing with any hysterisis values.  Matches each value above.
    enclosure_temp_recovery_hysterisis_value: 3        
    enclosure_humidity_recovery_hysterisis_value: 10
    cpu_temp_recovery_hysterisis_value: 5     
    battery_low_voltage_recovery_hysterisis_value: 2


backup_data_handling:        # This manages where the unwritten data gets stashed.
    nix_data_parking_area:  "/home/pi/Logs/log-messages.log"
    win_data_parking_area:  "c://temp//logs//log-messages.log"

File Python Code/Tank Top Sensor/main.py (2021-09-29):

# This is the micropython code for the PyCom LoPy4 module.  It does the following.
# - manages the sensor readings for the submersible pressure sensor as well as the various environmental sensors
# - periodically connects to TTN to report the data.


# Change history
# V1    2018-08-20  First attempt to consolidate test components.
# V2    2018-08-24  Added the extra check in the measure 2 loop.
# V3    2018-10-13  Reintroduce UART1 for serial logging.
# V4    2018-10-21  Introduced SHT31 readings
# V5    2018-11-07  Introduced error handler on LoRa join.
# V6    2020-02-01  Changed from ultrasonic to submersible sensor.
# V7    2021-02-17  Picked this up again in 2021, but with the LCD removed and ADS1115 used for A-D conversion.
# v8    2021-04-08  Deleted the code which explicitly set the LoRaWAN downlink channels (and fixed the repeatability issue)
# v9    2021-05-01  Created a separate JSON AppKeys file common to all registered devices to contain all AppKeys.
# v10   2021-05-02  Added a diagnostic loop to read all A-D channels when in offline mode (for testing).


import pycom
import utime
import time

import machine
from machine import UART
from machine import Timer
from machine import Pin
from machine import I2C

from network import LoRa
from network import WLAN
from network import Bluetooth

import sys
import socket
import ubinascii
import uos
import struct
import binascii
import json

import BME280
import ads1x15

import tank_sensor_config       # Local configuration file


'''
This is the overall flow of the application
- Startup.  We may have just woken from deep sleep, or been rebooted.  At
  present this is not significant, but we report it anyway.
- Capture the current time.  This is used later to determine how long the
  processing has taken, and so schedule the length of deep sleep time.
- Join the LoRa WAN.
- Startup the submersible sensor and get the pressure reading.
- Get the environmental readings (temp, humidity, pressure, battery, light)
- Transmit the data and then close the WAN.
- Go into deep sleep for the required interval.

Module physical pin connections used are as follows.  The corresponding
Pin Names are shown in parenthesis as (P17).
------------------------------------
Pin 5/6 = UART1 TX/RX for serial console.  Leave disconnected to minimise power drain.
Pin 10/13 = UART2 TX/RX. Not in use.
Pin 11/12 (P9, P10) = i2C bus.  (P9=SDA, P10=SCL)
Pin 22 (P20) = online or offline sense switch. Ground this to run offline.
Pin 23 (P21) = Boost converter enable (for 24V boost converter which powers the submersible sensor).
All the analog readings from sensors are converted to digital via the ADS1115 module
so none of the microcontoller analog inputs are needed.
'''

# ---- Analog channels used on ADS1115 Analog to Digital Converter ------------
# These define the channels used on the ADS1115 Analog to Digital Converter.
AD_CHANNEL_BATTERY_VOLTAGE = 0
AD_CHANNEL_TANK_PRESSURESENSOR = 1
AD_CHANNEL_LDR_SENSOR = 2
AD_CHANNEL_SPAREUNUSED = 3


# ---- Battery voltage conversion constant -------------------------------------
# This value is used to derive the actual battery voltage from the result 
# of the analog read from the voltage divider.
BATTERY_VOLTAGE_CONSTANT = 19.1056


# ---- Debug logger ------------------------------------------------------------
def c_log(logMessage):
    #logger.write(logMessage + "\n\r")
    print(logMessage + "\r")


# ---- Chrono snapshot --------------------------------------------------------
def chrono_snap():
    time_right_now = chrono.read()
    c_log("==> Chrono snap immediate value = {:.3f} Seconds.".format(time_right_now))



# ---- Generic LED flasher -----------------------------------------------------
def led_flasher(flash_state, flash_count, flash_message):
    '''
    This generic routine is mainly for error alerting.
    Red flash count values for errors are as follows
    5 = unused
    10 = LoRa join failure
    '''
    if (flash_state == 'E'):    # Error condition
        for i in range (flash_count):
            pycom.rgbled(0x500000) # Red flash to indicate error
            time.sleep(0.1)
            pycom.rgbled(0x000000)
            time.sleep(0.1)
    '''
    Blue flash count values for status messages already implemented
    10 = about to hibernate
    '''
    if (flash_state == 'S'):       # Just a status indicator
        for i in range (flash_count):
            pycom.rgbled(0x000050) # Blue flash to indicate status
            time.sleep(0.15)
            pycom.rgbled(0x000000)
            time.sleep(0.15)


# ---- LED Rainbow function -----------------------------------------------------
def led_rainbow():
    # This just increments and decrements the onboard LED to create a pretty effect
    c_log("LED Rainbow pattern")

    # Red increase to 255
    for i in range(0, 255):
        pycom.rgbled(0 + i*65536)       # Increment red
        time.sleep(0.005)
    
    # Red decrease to 0 while green increase to 255
    for i in range(0, 255):
        pycom.rgbled((16711680 - i*65536) + (i*256))    # Decrement red and increment green
        time.sleep(0.005)
    
    # Green decrease to 0 while blue increases to 255
    for i in range(0, 255):
        pycom.rgbled((65280 - i*256) + i)    # Decrement green and increment blue
        time.sleep(0.005)
    
    # Blue decreases to 0 
    for i in range(0, 255):
        pycom.rgbled((255 - i))    # Decrement blue 
        time.sleep(0.005)

    c_log("LED Rainbow complete")


# ---- String manipulation -----------------------------------------------------
def rawbytes(s):
    # Convert a string to raw bytes without encoding
    outlist = []
    for cp in s:
        num = ord(cp)
        if num < 255:
            outlist.append(struct.pack('b', num))
        elif num < 65535:
            outlist.append(struct.pack('>H', num))
        else:
            b = (num & 0xFF0000) >> 16
            H = num & 0xFFFF
            outlist.append(struct.pack('>bH', b, H))
    return b''.join(outlist)



# ---- Get the AppKey needed by this device from the external AppKeys file
def get_my_appkey(arg_appkey_file, arg_loramac):
    c_log("  AppKey file to search [" + arg_appkey_file + "].")
    c_log("  Device EUI to find    [" + arg_loramac + "].")
    try:
        with open(arg_appkey_file) as json_file:
            appkey_data = json.load(json_file)
            localMyAppKey = ubinascii.unhexlify(appkey_data["" + arg_loramac + ""])
            c_log("  Found required AppKey for this Device EUI.")
            return localMyAppKey
    except:
        c_log("ERROR 902.  The requiured AppKey was not found in the file.  Terminating now.")   
        sys.exit(902)
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

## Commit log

2021-09-29 Add files via upload
    KiCad Schematics and PCB layout files
    [Pump Control and Solar Monitor G1.kicad_pcb, Pump Control and Solar Monitor G1.sch, Pump Remote Control Box G1.kicad_pcb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]
2021-09-29 Add files via upload
    Python and micropython code for each component
    [PumpController.yaml]

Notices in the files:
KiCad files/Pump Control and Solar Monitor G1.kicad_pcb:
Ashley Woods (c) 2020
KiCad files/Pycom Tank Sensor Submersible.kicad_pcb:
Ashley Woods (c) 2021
